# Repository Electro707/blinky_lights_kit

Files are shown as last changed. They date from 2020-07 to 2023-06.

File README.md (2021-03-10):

# Blinky Lights Kit

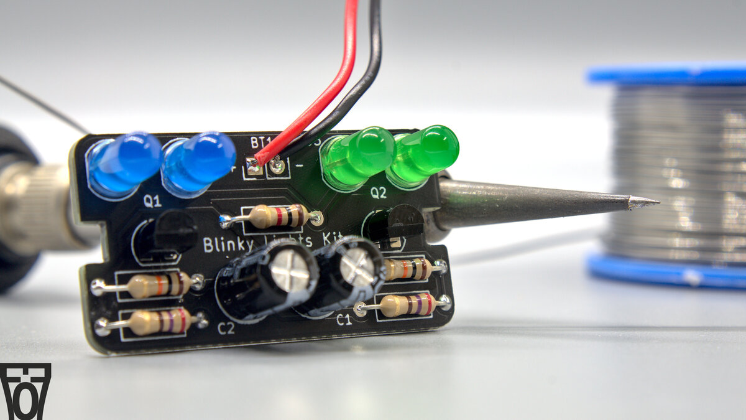
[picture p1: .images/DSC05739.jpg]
Product Image


Welcome to the main repository for the Blinking Lights Kit. Here you will find everything that was used to make the project/kit come to life, from the KiCad file to the instruction's SVGs.

See [HERE](https://kits.electro707.com/blinky_lights/) for the project's page and documentation (including soldering instructions).

### Kit on Tindie
I am currently selling the kit on Tindie. The product page can be found at [https://www.tindie.com/products/20887/](https://www.tindie.com/products/20887/).

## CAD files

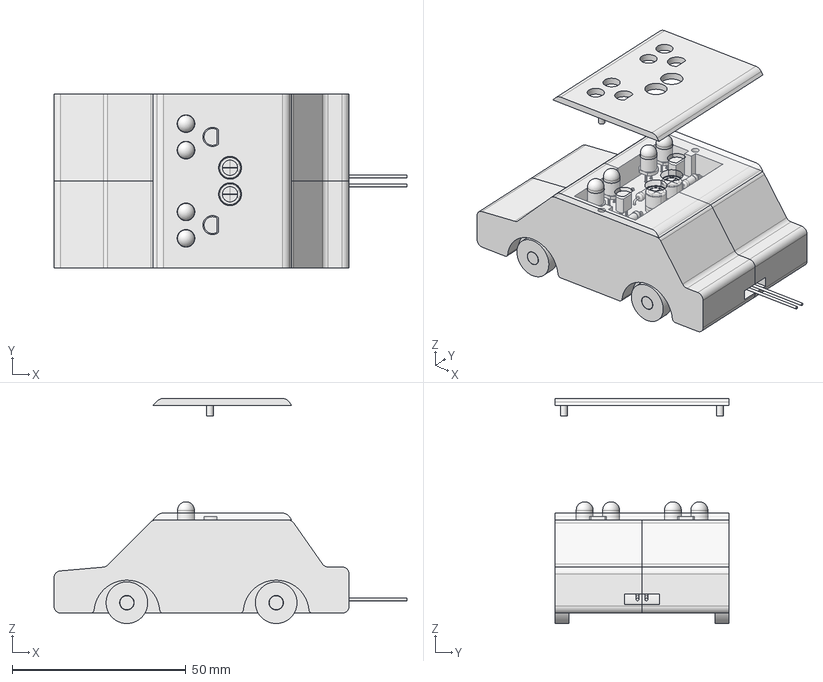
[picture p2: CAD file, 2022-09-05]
Enclosure-FreeCAD/CarCase/Assembly.FCStd
101.7 x 50.0 x 64.8 mm
Car_Body001_002
Car_Body002_004
Car_Body004_001
Car_Body002_003
Car_Body003_001
Car_Body002_001
Car_Body001_001
LightTop_001
Car_Body002_002
PCB1_001

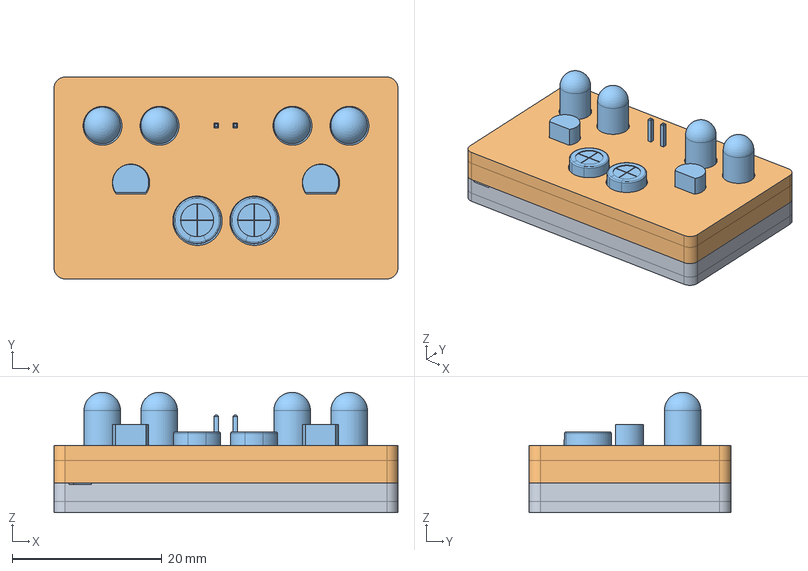
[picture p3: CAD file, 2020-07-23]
Enclosure-FreeCAD/RectangularCase/Assembly.FCStd
46.0 x 27.0 x 16.1 mm
Buttom_001
Top_001
PCB1_001

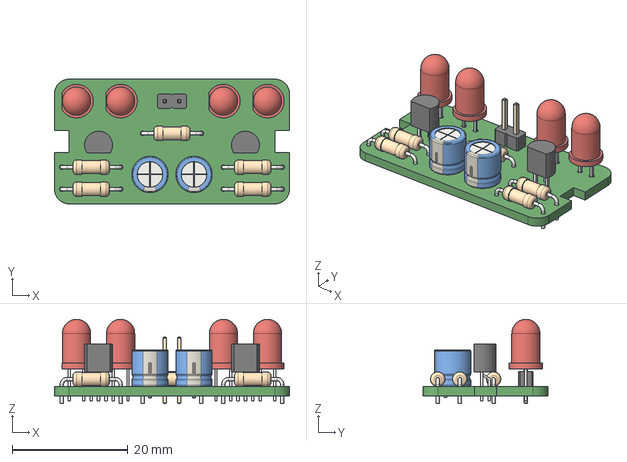
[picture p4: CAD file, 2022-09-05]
Enclosure-FreeCAD/PCB.step
40.6 x 21.6 x 14.6 mm

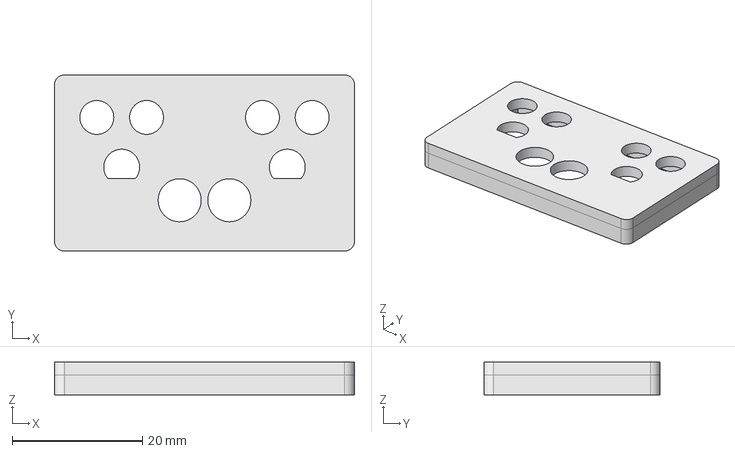
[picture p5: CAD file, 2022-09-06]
Enclosure-FreeCAD/RectangularCase/Top.FCStd
46.0 x 27.0 x 5.00 mm

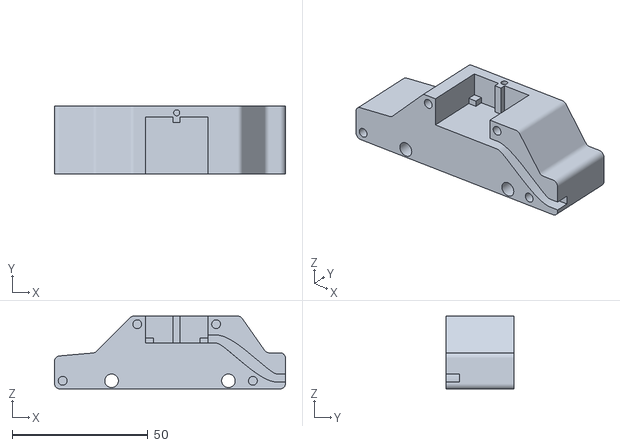
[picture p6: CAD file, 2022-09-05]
Enclosure-STL/Car Enclosure/CarBodyLeft.stl
85.0 x 25.0 x 26.8

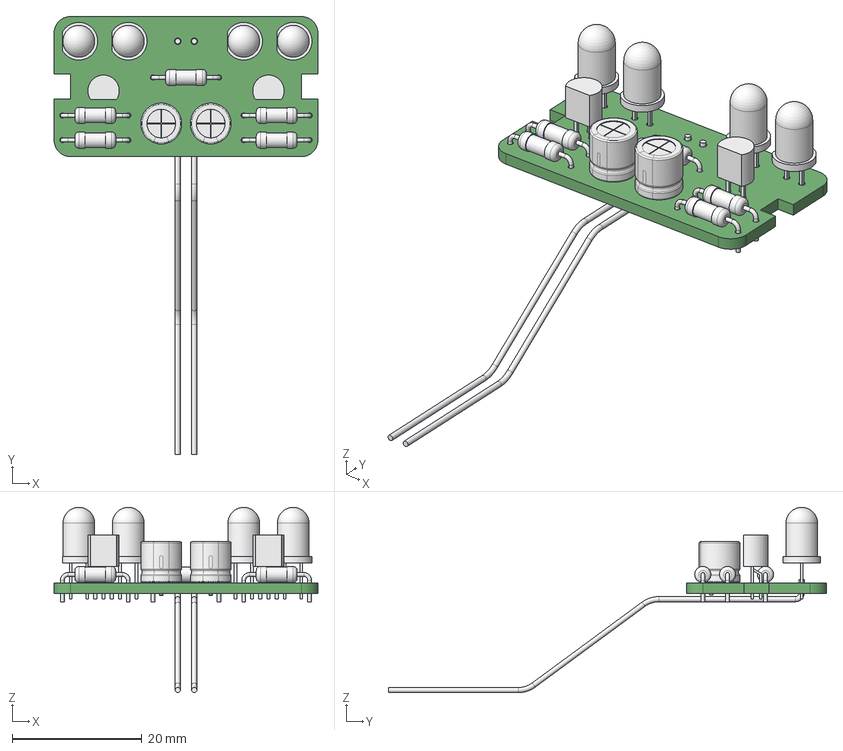
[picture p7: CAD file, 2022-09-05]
Enclosure-FreeCAD/CarCase/PCB_w_Wire.FCStd
40.6 x 67.5 x 28.5 mm

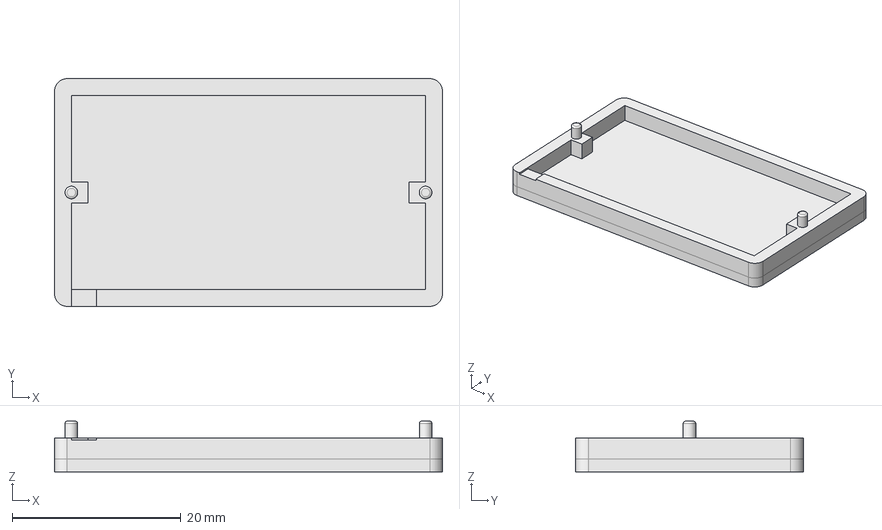
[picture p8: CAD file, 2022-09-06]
Enclosure-FreeCAD/RectangularCase/Buttom.FCStd
46.0 x 27.0 x 6.00 mm

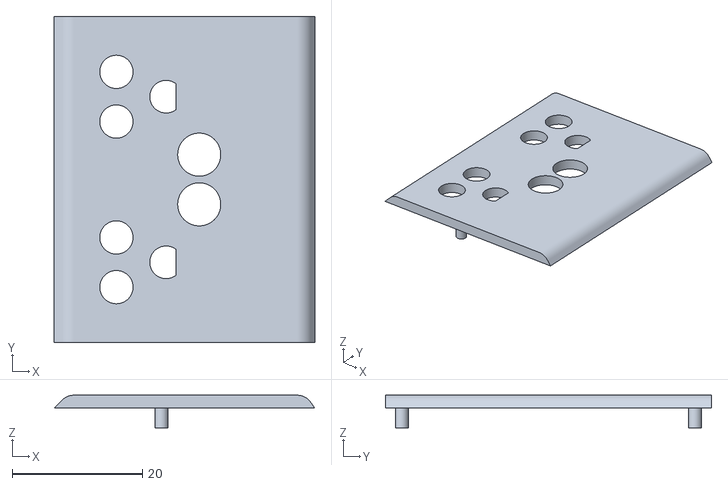
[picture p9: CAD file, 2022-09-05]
Enclosure-STL/Car Enclosure/CarTop.stl
40.0 x 50.0 x 5.00

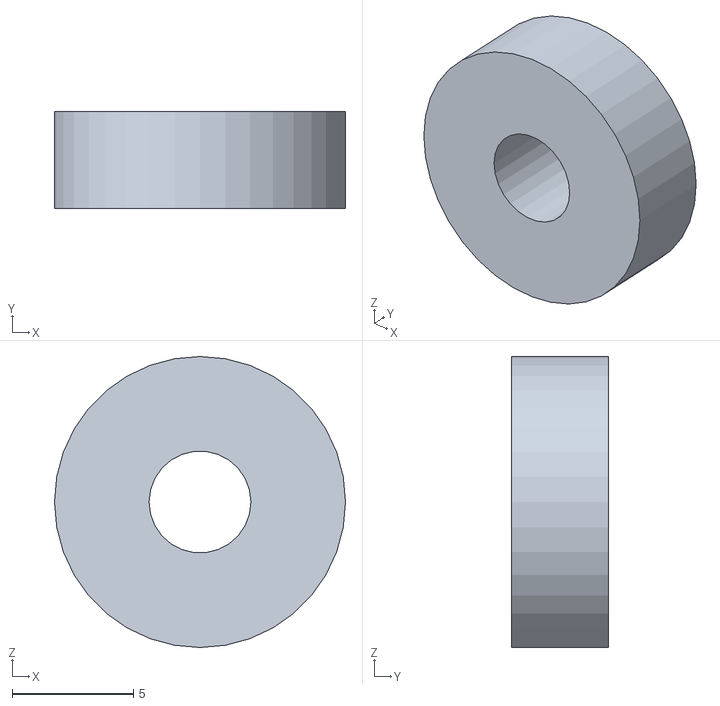
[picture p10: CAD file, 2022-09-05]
Enclosure-STL/Car Enclosure/CarWheel.stl
12.0 x 4.00 x 12.0

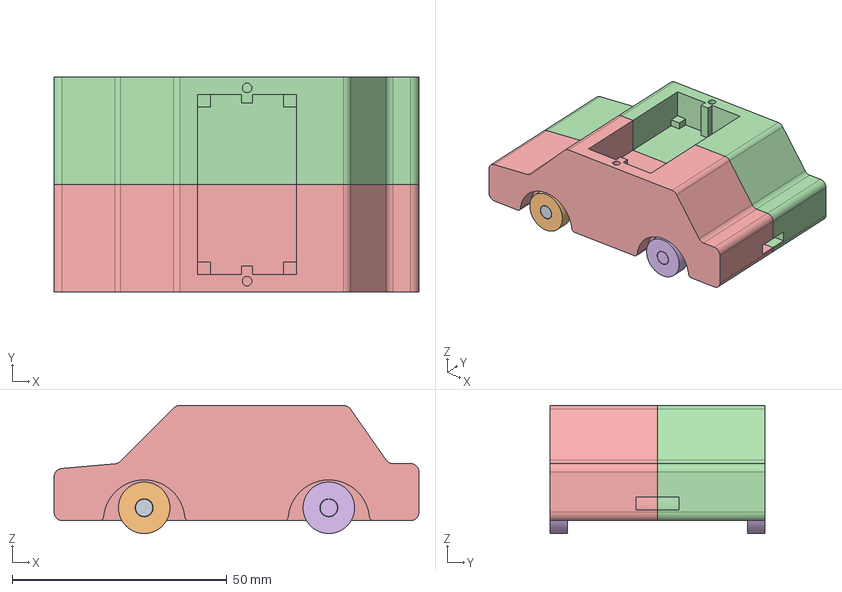
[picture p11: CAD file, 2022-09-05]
Enclosure-FreeCAD/CarCase/Car.FCStd
85.0 x 50.0 x 29.8 mm
WheelBack

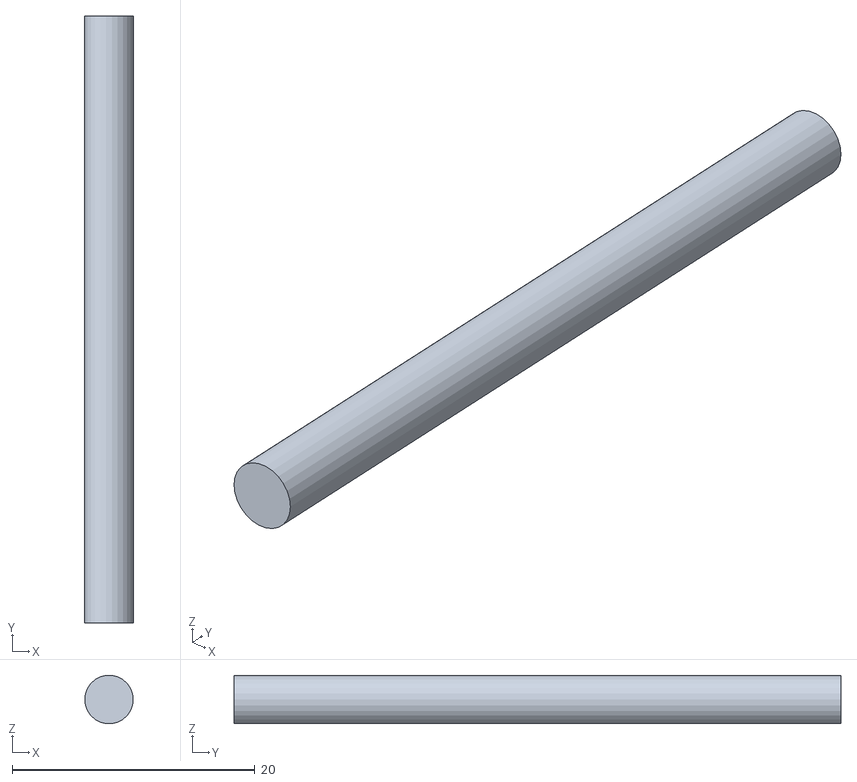
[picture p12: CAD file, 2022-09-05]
Enclosure-STL/Car Enclosure/CarShaft.stl
4.00 x 50.0 x 3.97

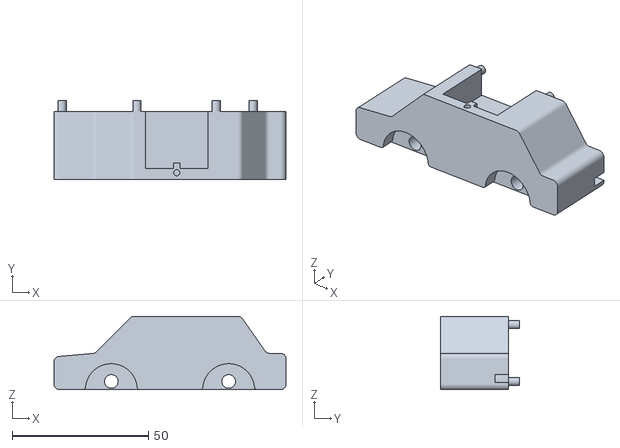
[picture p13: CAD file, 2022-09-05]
Enclosure-STL/Car Enclosure/CarBodyRight.stl
85.0 x 29.0 x 26.8

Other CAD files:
Enclosure-STL/Rectangular Enclosure/Top.stl
Enclosure-STL/Rectangular Enclosure/Bottom.stl
Enclosure-FreeCAD/CarCase/LightTop.FCStd

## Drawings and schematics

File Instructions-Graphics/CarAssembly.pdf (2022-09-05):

# Blinking Lights Car

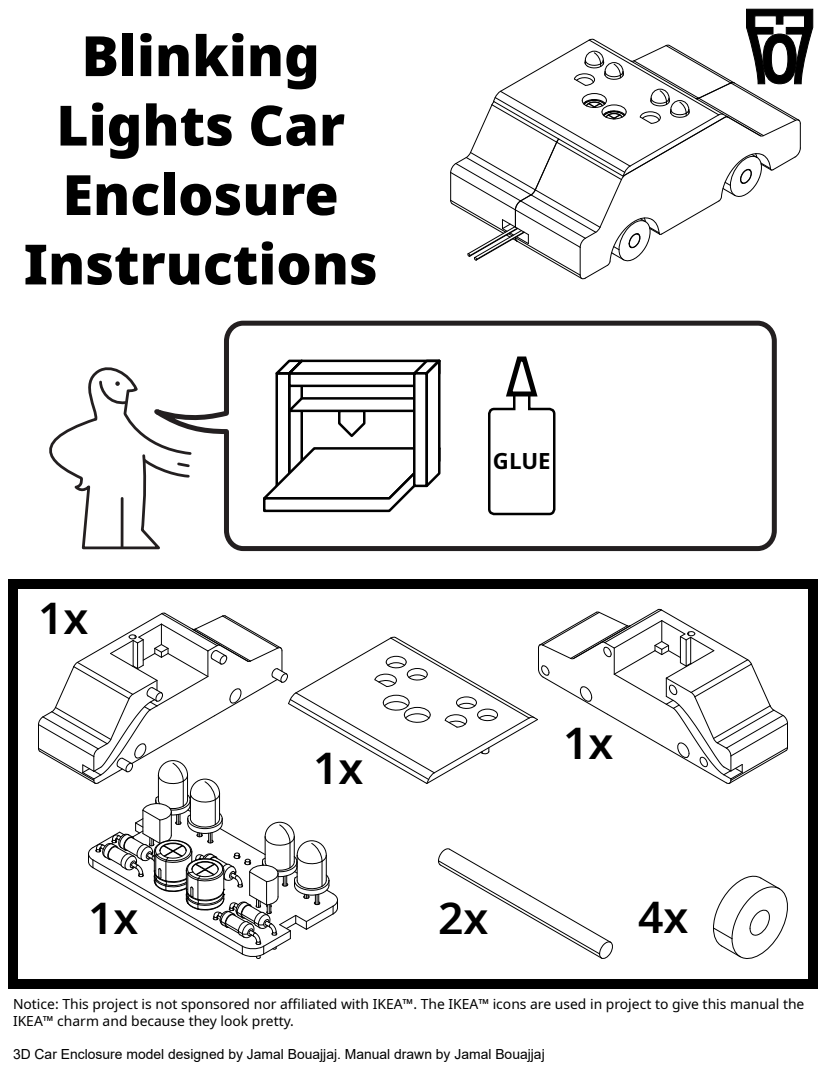
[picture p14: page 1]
GLUE; Enclosure Instructions

Notice: This project is not sponsored nor affiliated with IKEA™. The IKEA™ icons are used in project to give this manual the
IKEA™ charm and because they look pretty.

3D Car Enclosure model designed by Jamal Bouajjaj. Manual drawn by Jamal Bouajjaj

1 2

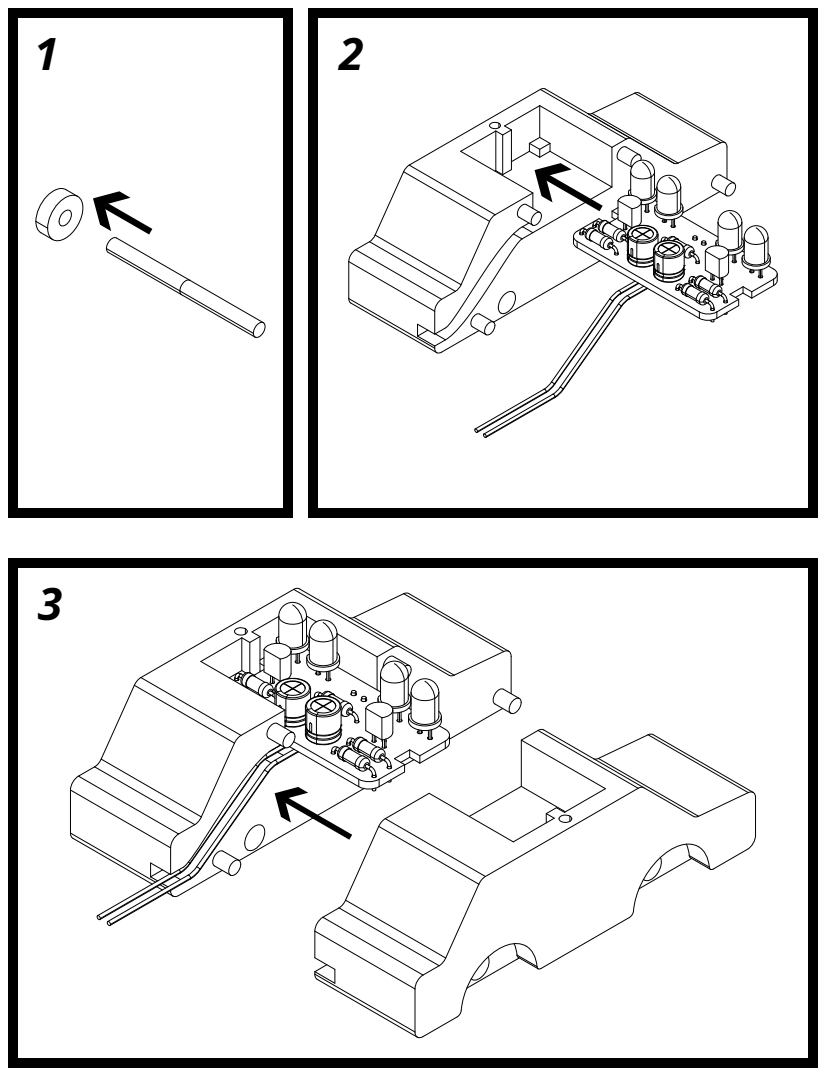
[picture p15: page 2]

45

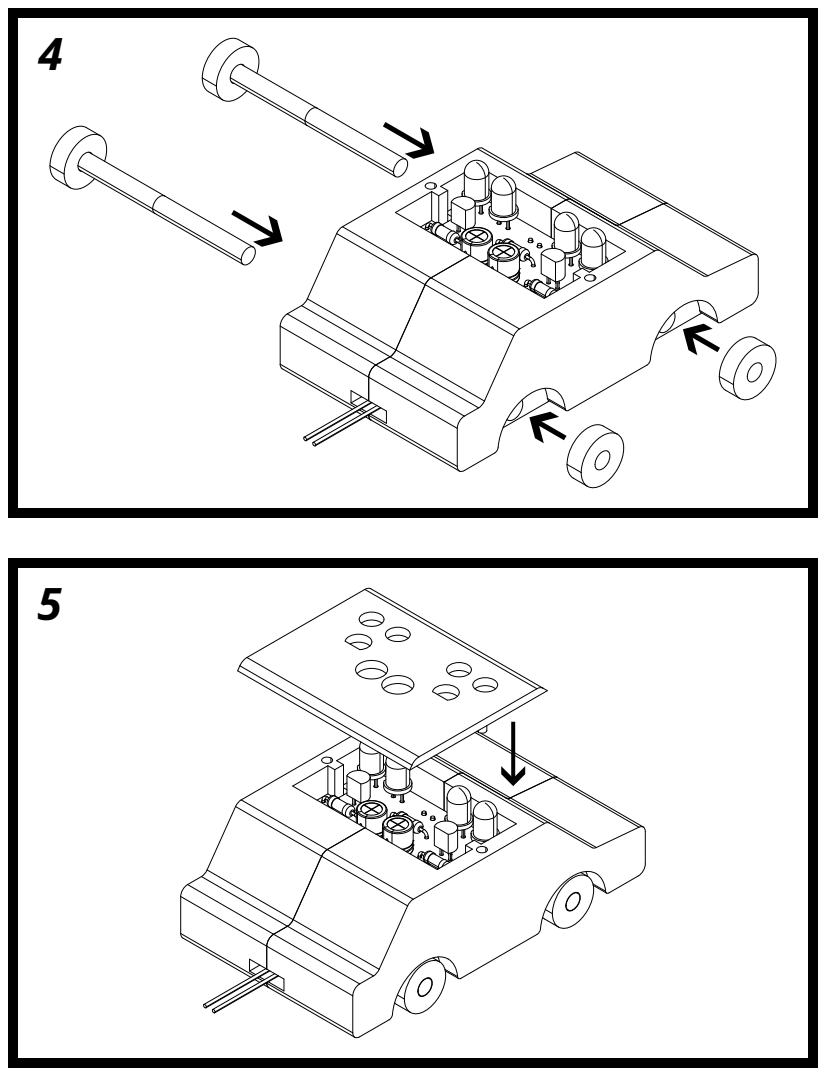
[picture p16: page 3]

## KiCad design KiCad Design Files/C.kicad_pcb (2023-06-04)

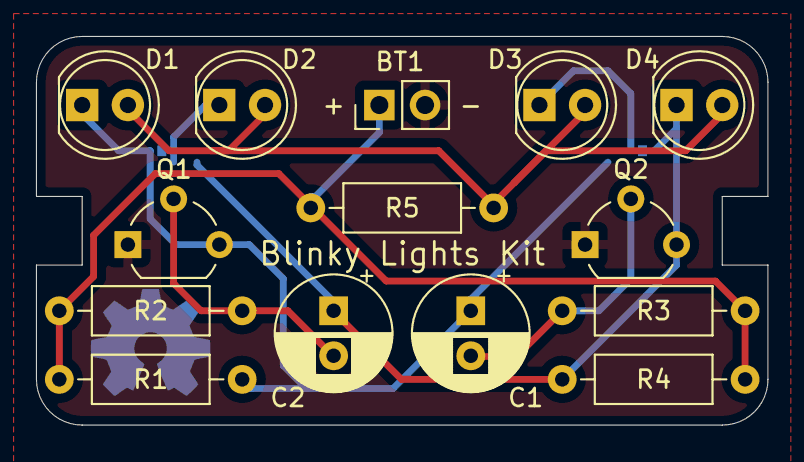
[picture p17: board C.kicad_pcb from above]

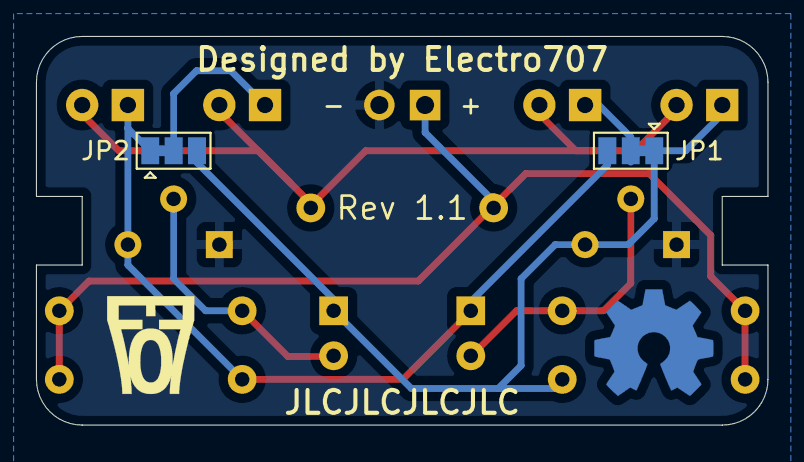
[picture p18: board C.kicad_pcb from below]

Board: 2 copper layers, 40.6 x 21.6 mm, 16 parts (2 on the bottom side), 9 nets.

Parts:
BT1: Battery; PinHeader_1x02_P2.54mm_Vertical
C1, C2: 100uF; CP_Radial_D6.3mm_P2.50mm
D1, D2, D3, D4: LED; LED_D5.0mm
JP1, JP2: SolderJumper_3_Bridged12; SolderJumper-3_P1.3mm_Bridged12_Pad1.0x1.5mm
Q1, Q2: 2N3904; TO-92_Wide
R1, R4: 270; R_Axial_DIN0207_L6.3mm_D2.5mm_P10.16mm_Horizontal
R2, R3: 10k; R_Axial_DIN0207_L6.3mm_D2.5mm_P10.16mm_Horizontal
R5: 1k; R_Axial_DIN0207_L6.3mm_D2.5mm_P10.16mm_Horizontal

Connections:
C1: C1.1, D1.1 (K), JP1.1 (A), JP2.3 (B), Q1.3 (C), R1.2
C2: C2.1, D4.1 (K), JP1.3 (B), JP2.1 (A), Q2.3 (C), R4.2
GND: BT1.2 (-), Q1.1 (E), Q2.1 (E)
unnamed: C1.2, Q2.2 (B), R3.2
unnamed: C2.2, Q1.2 (B), R2.2
unnamed: D1.2 (A), D2.2 (A), D3.2 (A), D4.2 (A), R5.2
unnamed: D2.1 (K), JP1.2 (C)
unnamed: D3.1 (K), JP2.2 (C)
VCC: BT1.1 (+), R1.1, R2.1, R3.1, R4.1, R5.1

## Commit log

2021-12-09 Updated schematic, 100k to 10k. Added right title block
    [C.sch]
2022-06-19 Updated files to KiCAD 6.0 and updated board to rev 1.1
    Rev 1.1 includes the following changes:
    - Minor silkscreen changes and component movement
    - Mainly changed the TO92 package to one which is easier to solder
    [C.kicad_pcb, C.kicad_sch, C.sch]
2022-09-05 Updated Gerber files for Rev1.1. Added a car enclosure and assembly drawing
    [Assembly.FCStd, Buttom.FCStd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]
2022-09-06 Updated Rectangular enclosure and added STL files
    [Bottom.stl, Buttom.FCStd, Top.FCStd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]
2023-06-04 Added a JLCJLCJLCJLC silkscreen for ordering from JLC Removed Gerber and SVG files from git tracking KiCad updated some file's syntax and internal version to latest 6.x
    [C-B_Cu.gbr, C-B_Mask.gbr, C-B_Silkscreen.gbr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]
